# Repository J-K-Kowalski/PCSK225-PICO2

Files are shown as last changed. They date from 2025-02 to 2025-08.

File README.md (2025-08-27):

# PCSK225-PICO2 SDR Receiver

<ul>
<li>2025-08-27 - Documentation</li>
<li>2025-02-25 - First version of the project</li>
</ul>

## Overview

<p>PCSK225-PICO2 is a compact, low‑cost software defined receiver designed to decode the 225 kHz Polish time signal transmitted from Solec Kujawski. The design is built around the Raspberry Pi Pico 2 (RP2350) module and supports two signal acquisition paths:

- Direct sampling with a high‑speed external ADC (ADS7049)
- Optional SSB down‑conversion using a Si4537‑D60 tuner, enabling baseband sampling with the RP2350’s internal ADC

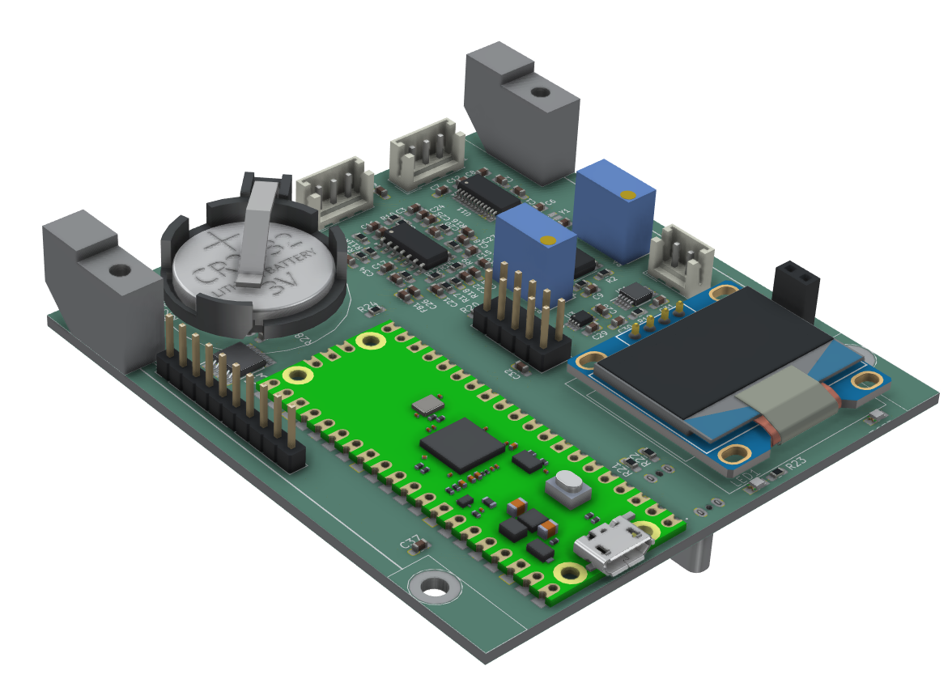
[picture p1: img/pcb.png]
 

<p>The board integrates a precision RTC, local display, I/O expansion, audio output, and multiple user I/Os, making it a self‑contained platform for time‑signal experiments and SDR development.

## Key Features

- MCU: Raspberry Pi Pico 2 (RP2350) module
- Direct RF sampling: ADS7049 12‑bit, high‑speed SPI ADC connected to the RP2350 (supports ~225 kHz IF/baseband sampling)
- Optional tuner: Si4537‑D60 for SSB-style down‑conversion to low IF/baseband for sampling by the RP2350 internal ADC
- RF front end:
    - Active 6‑pole Butterworth band‑pass amplifier around TLV9064 (U2) centered on 225 kHz
    - Output/driver amplifier for Si4537 based on TLV9062 (U1)
    - TMUX1204 analog multiplexer (IC1) for flexible signal routing between ADCs and front‑end nodes
- Timing: DS3231 RTC with CR2032 backup battery for stable timekeeping and 1 Hz/32 kHz outputs
- Displays:
    - On‑board 0.96" I2C OLED (SSD1306)
    - Header for an external graphic LCD
- I/O expansion and storage:
    - PCA9500 I2C port expander with integrated EEPROM for configuration storage
- Connectivity and power:
    - Micro‑USB (Pico 2)
    - USB‑C connector for powering the receiver and PC connectivity
- User I/O:
    - 8 general‑purpose digital I/O lines on headers
    - PWM‑driven speaker/buzzer output with buffer stage
- Form factor: single PCB with Pico 2 module, mounting holes, and on‑board connectors
- See pcb.jpg for a 3D view of the assembled board

## Signal Paths

- Direct 225 kHz path:

1) Antenna/RF input → active BPF (U2 TLV9064) → analog mux (IC1) → ADS7049 → RP2350 via SPI/DMA
2) Intended for coherent sampling/decoding of the Polish 225 kHz time code
- Optional SSB/down‑conversion path:

1) RF input → Si4537‑D60 → low‑IF/baseband → output amplifier (U1 TLV9062) → RP2350 internal ADC
2) Useful for alternative demodulation modes and experiments

## Subsystem Details

- Active BPF: 6‑pole Butterworth around 225 kHz using TLV9064 quad op‑amp, input protection, and gain‑setting network
- Analog MUX: TMUX1204 routes filtered RF to the external ADC or other measurement points
- External ADC: ADS7049 low‑latency, SPI, suited for continuous streaming to RP2350 (DMA recommended)
- RTC: DS3231SN provides INT/SQW and 32 kHz outputs; backed by CR2032 cell
- Displays:
    - SSD1306 OLED on I2C bus (address configurable via jumpers)
    - External LCD header with SPI/I2C signals as routed on the schematic
- I2C Expander/EEPROM: PCA9500 provides extra GPIO and non‑volatile storage for calibration and user settings
- Audio: small speaker output driven from MCU PWM through a buffer (74LVC1G34) and filtering
- Power:
    - 3V3 rail with local decoupling (X5R/COG capacitors as noted)
    - USB‑C and Micro‑USB power options; VSYS routed to Pico 2
    - Ferrite bead and RC elements for analog rail cleanliness

## Firmware Notes

- Platform: Arduino core for RP2040/RP2350 or Pico SDK (C/C++)
- Recommended peripherals:
    - SPI DMA for ADS7049 streaming
    - PIO or timers for precise sampling clocks if needed
    - I2C for OLED, RTC, and PCA9500
    - PWM for speaker/buzzer output
- Example tasks:
    - 225 kHz band‑limited sampling and digital demodulation/decoding (e‑Czas/time code)
    - SSB/low‑IF capture via Si4537 with on‑chip ADC
    - UTC timekeeping using DS3231 and PPS alignment

## Connectors and Interfaces

- Pico 2 module header exposes GP0…GP21, ADC pins, SWD, 3V3, VBUS, VSYS
- OLED I2C header and external LCD header
- USB‑C and Micro‑USB
- 8x GPIO header for user applications
- RF input and test headers as shown on the schematic
- Speaker/buzzer connector

## Bill of Main ICs

- RP2350 (Raspberry Pi Pico 2 module)
- ADS7049 (external high‑speed ADC)
- Si4537‑D60 (optional tuner/down‑converter)
- TLV9064 (quad op‑amp, BPF and buffering)
- TLV9062 (dual op‑amp, output driver)
- TMUX1204 (analog multiplexer)
- DS3231SN (RTC)
- PCA9500 (I2C GPIO expander + EEPROM)
- SSD1306 (OLED controller)

## Status

- Hardware: Rev. 2 schematic/PCB
- Image: see pcb.jpg for the assembled PCB render
- Firmware: work in progress

## License

- Hardware and firmware: A permissive license similar to the BSD 2-Clause License, but with a 3rd clause that prohibits others from using the name of the copyright holder or its contributors to promote derived products without written consent.

## Acknowledgements

- Designed by <b>KJK Innovations</b> for research and development of low‑frequency time‑signal receivers and SDR experimentation.

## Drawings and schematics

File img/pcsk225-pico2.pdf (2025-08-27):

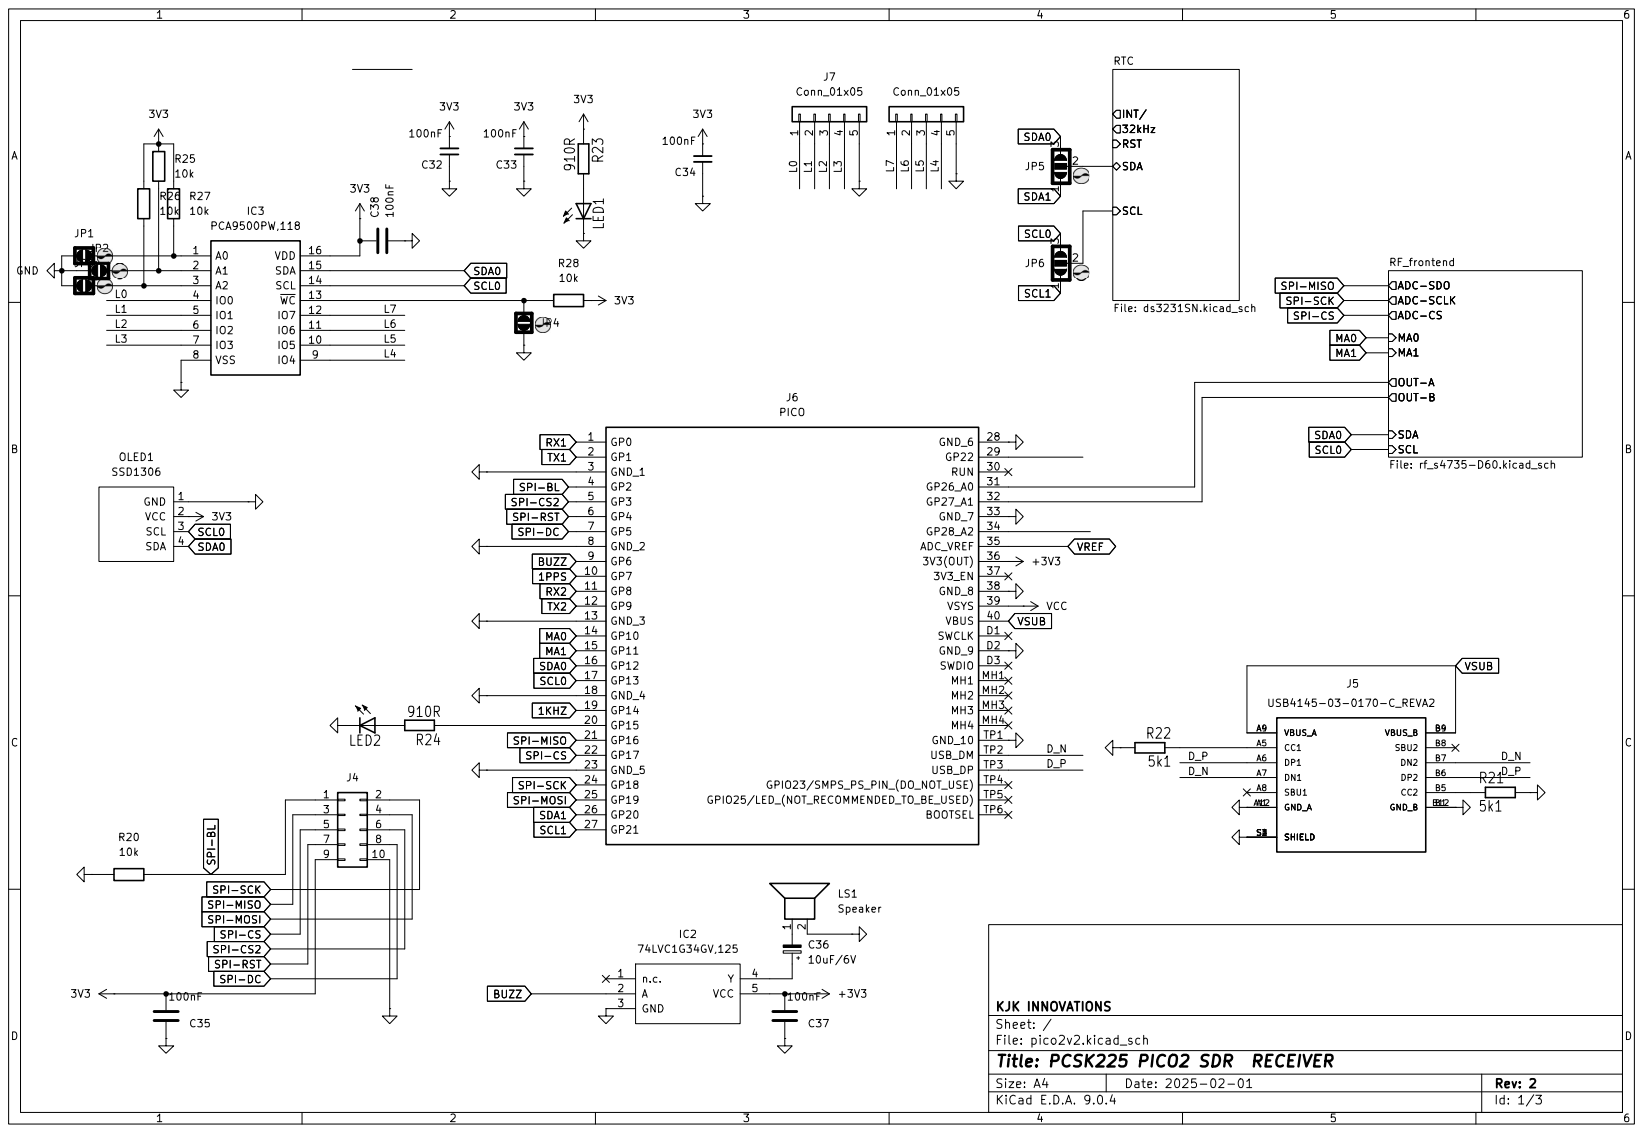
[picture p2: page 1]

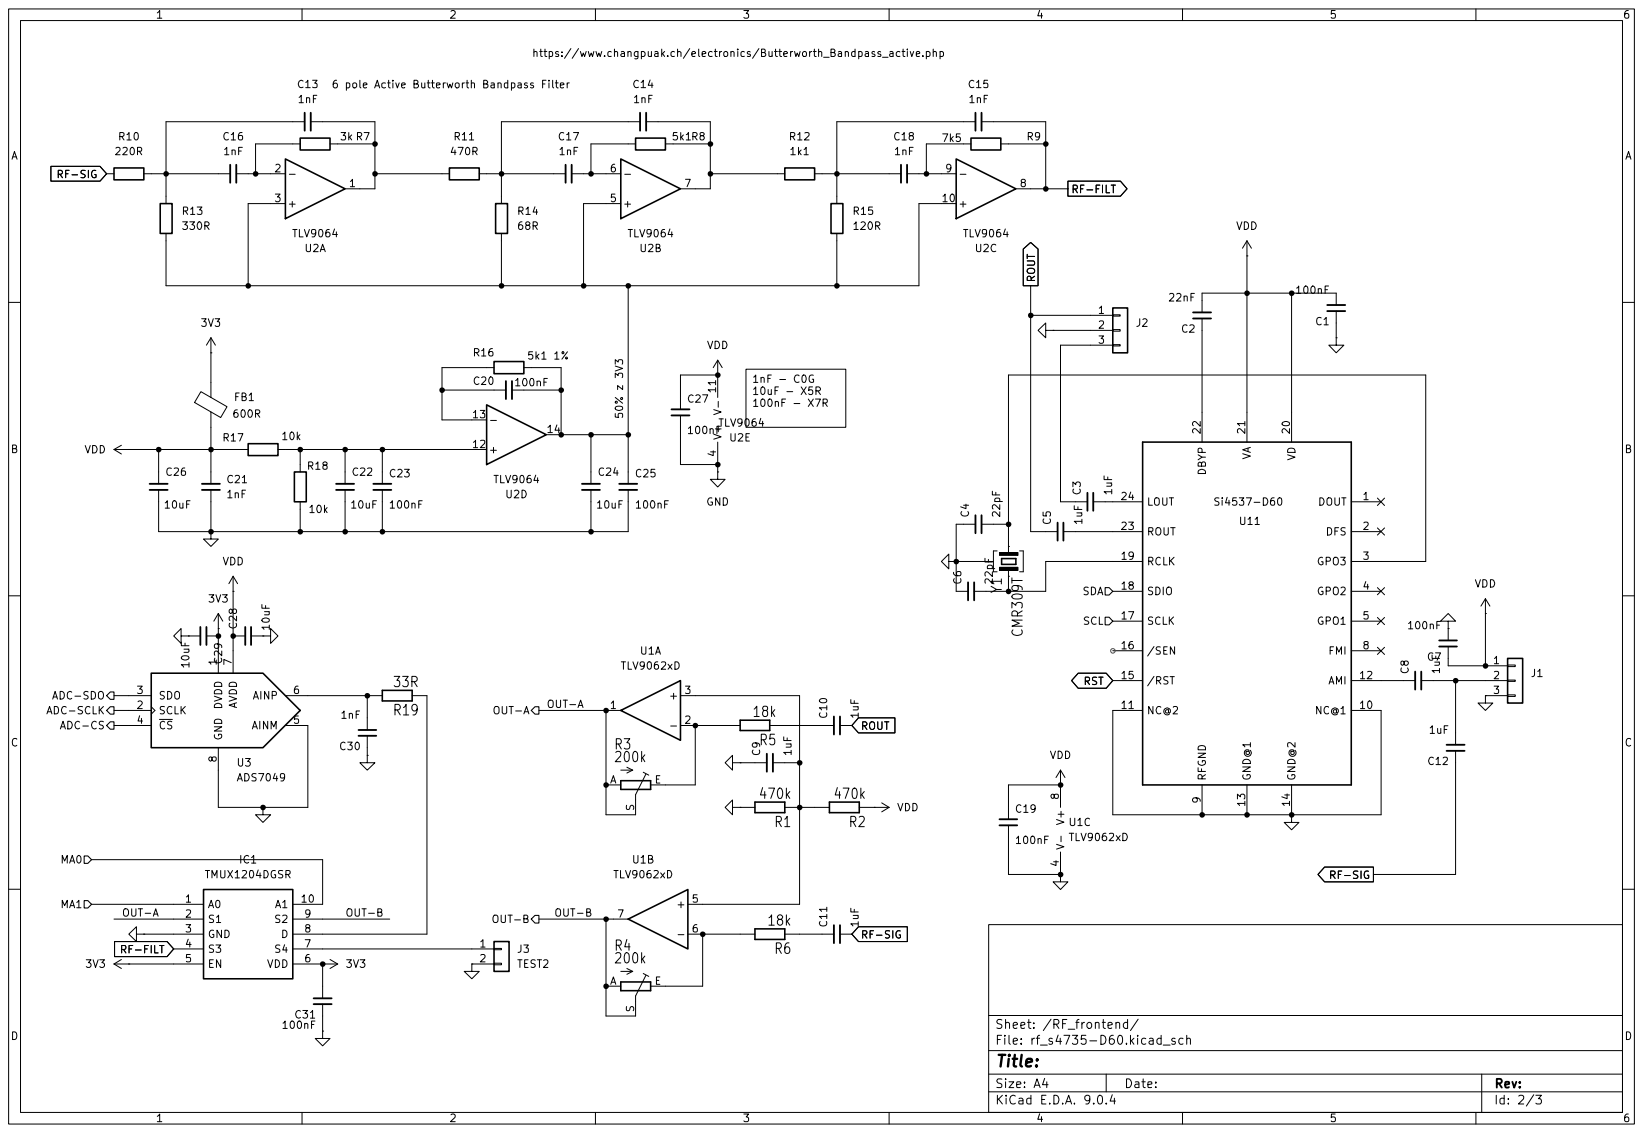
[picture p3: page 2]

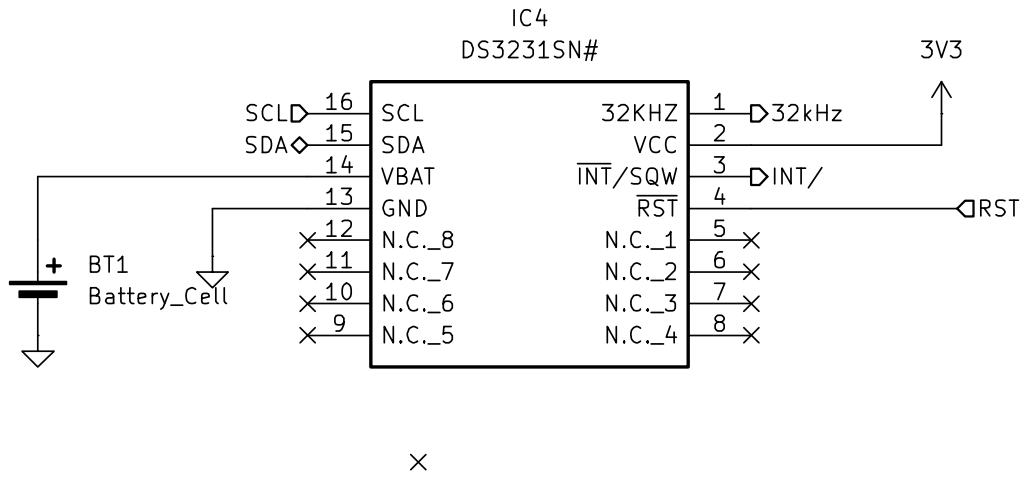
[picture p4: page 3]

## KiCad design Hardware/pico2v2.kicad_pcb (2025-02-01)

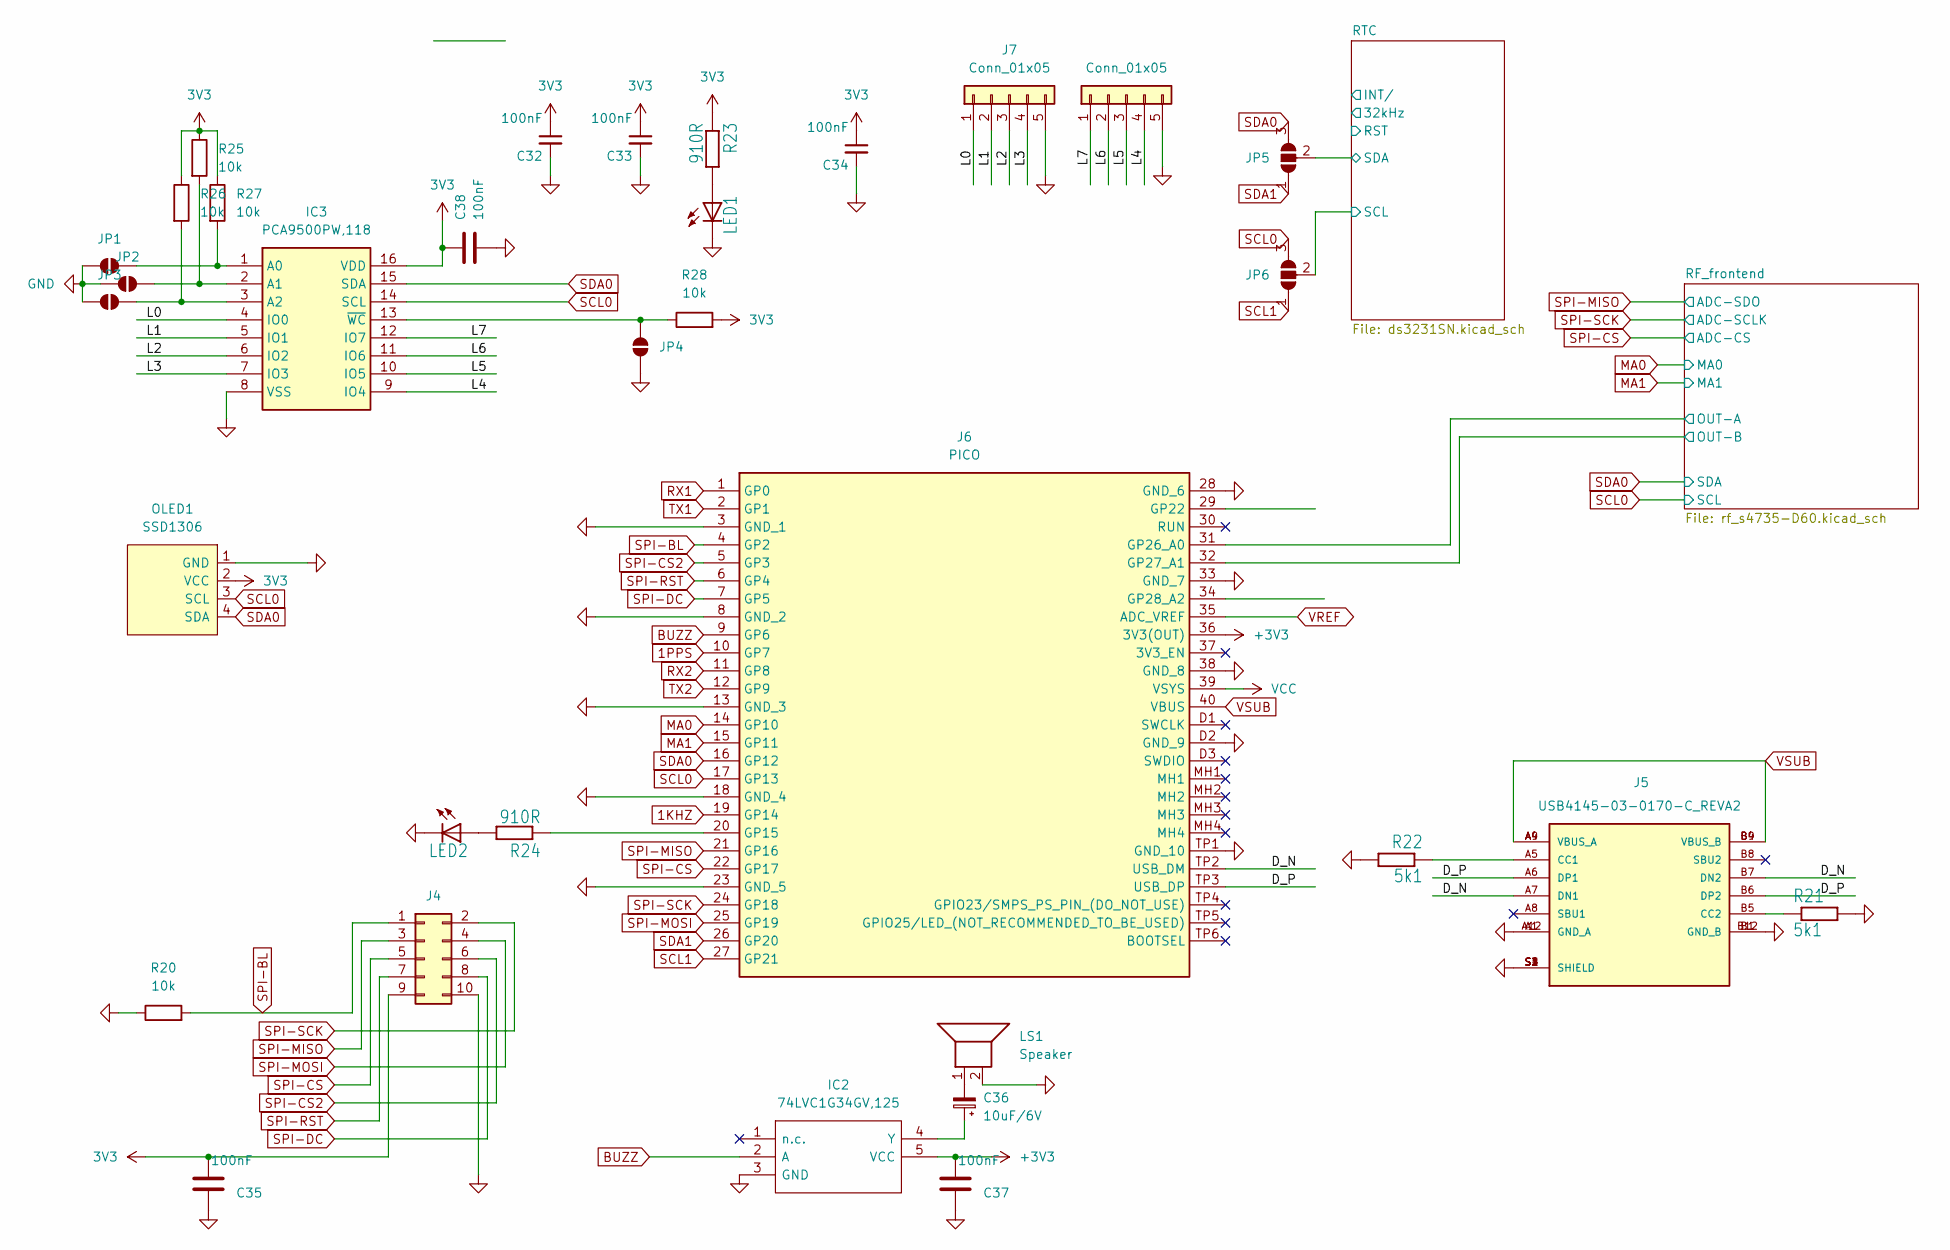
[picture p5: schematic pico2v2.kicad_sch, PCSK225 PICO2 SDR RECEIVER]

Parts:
C32, C33, C34, C35, C37, C38: 100nF; C_0603_1608Metric_Pad1.08x0.95mm_HandSolder
C36: 10uF/6V; C_0805_2012Metric_Pad1.18x1.45mm_HandSolder
Connector_PinHeader_2.54mm:PinHeader_1x05_P2.54mm_Vertical1: Conn_01x05; PinHeader_1x05_P2.54mm_Vertical
IC2: 74LVC1G34GV,125; SOT95P275X110-5N; Manufacturer_Part_Number 74LVC1G34GV,125; Mouser Part Number 771-LVC1G34GV125
IC3: PCA9500PW,118; SOP65P640X110-16N; Mouser Part Number 771-PCA9500PW-T
J4: Conn_02x05_Odd_Even; PinHeader_2x05_P2.54mm_Vertical
J5: USB4145-03-0170-C_REVA2; GCT_USB4145-03-0170-C_REVA2; PARTREV A2
J6: PICO; Manufacturer_Part_Number PICO
J7: Conn_01x05; PinHeader_1x05_P2.54mm_Vertical
JP1, JP2, JP3, JP4: SolderJumper_2_Open; SolderJumper-2_P1.3mm_Open_RoundedPad1.0x1.5mm
JP5, JP6: SolderJumper_3_Open; SolderJumper-3_P1.3mm_Open_RoundedPad1.0x1.5mm
LED1, LED2: LEDCHIPLED_0805; CHIP-LED0805
LS1: Speaker; PinSocket_1x02_P2.54mm_Vertical
OLED1: SSD1306; 128x64OLED
R20, R25, R26, R27, R28: 10k; R_0603_1608Metric_Pad0.98x0.95mm_HandSolder
R21, R22: 5k1; R_0603_1608Metric_Pad0.98x0.95mm_HandSolder
R23, R24: 910R; R_0603_1608Metric_Pad0.98x0.95mm_HandSolder

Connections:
1KHZ: J6.19 (GP14)
1PPS: J6.10 (GP7)
3V3: C32.1, C33.1, C34.1, C35.2, C38.1, IC3.16 (VDD), J4.9, OLED1.2 (VCC), R23.1, R25.1, R26.1, R27.1, R28.2; also elsewhere on the board
+3V3: C37.2, IC2.5 (VCC), J6.36 (3V3(OUT))
/D_N: J5.A7 (DN1), J5.B7 (DN2), J6.42, J6.TP2 (USB_DM)
/D_P: J5.A6 (DP1), J5.B6 (DP2), J6.42, J6.TP3 (USB_DP)
/L0: IC3.4 (IO0), J7.1
/L1: IC3.5 (IO1), J7.2
/L2: IC3.6 (IO2), J7.3
/L3: IC3.7 (IO3), J7.4
/L4: Connector_PinHeader_2.54mm:PinHeader_1x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.4, IC3.9 (IO4)
/L5: Connector_PinHeader_2.54mm:PinHeader_1x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.3, IC3.10 (IO5)
/L6: Connector_PinHeader_2.54mm:PinHeader_1x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.2, IC3.11 (IO6)
/L7: Connector_PinHeader_2.54mm:PinHeader_1x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.1, IC3.12 (IO7)
/RF_frontend/OUT-A: J6.31 (GP26_A0); also elsewhere on the board
/RF_frontend/OUT-B: J6.32 (GP27_A1); also elsewhere on the board
/RTC/SCL: JP6.2 (C); also elsewhere on the board
/RTC/SDA: JP5.2 (C); also elsewhere on the board
BUZZ: IC2.2 (A), J6.9 (GP6)
GND: C32.2, C33.2, C34.2, C35.1, C37.1, C38.2, Connector_PinHeader_2.54mm:PinHeader_1x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.5, IC2.3 (GND), IC3.8 (VSS), J4.10, J5.A1 (GND_A), J5.A12 (GND_A), J5.B1 (GND_B), J5.B12 (GND_B), J5.S1 (SHIELD), J5.S2 (SHIELD), J5.S3 (SHIELD), J5.S4 (SHIELD), J6.3 (GND_1), J6.8 (GND_2), J6.13 (GND_3), J6.18 (GND_4), J6.23 (GND_5), J6.28 (GND_6), J6.33 (GND_7), J6.38 (GND_8), J6.42, J6.D2 (GND_9), J6.TP1 (GND_10), J7.5, JP1.2 (B), JP2.2 (B), JP3.2 (B), JP4.2 (B), LED1.C, LED2.C, LS1.2, OLED1.1 (GND), R20.1, R21.2, R22.2; also elsewhere on the board
MA0: J6.14 (GP10); also elsewhere on the board
MA1: J6.15 (GP11); also elsewhere on the board
unnamed: C36.2, LS1.1
unnamed: C36.1, IC2.4 (Y)
unnamed: IC3.1 (A0), JP1.1 (A), R27.2
unnamed: IC3.2 (A1), JP2.1 (A), R25.2
unnamed: IC3.3 (A2), JP3.1 (A), R26.2
unnamed: IC3.13 (~WC), JP4.1 (A), R28.1
unnamed: J5.A5 (CC1), R22.1
unnamed: J5.B5 (CC2), R21.1
unnamed: J6.20 (GP15), R24.1
unnamed: LED1.A, R23.2
unnamed: LED2.A, R24.2
RX1: J6.1 (GP0)
RX2: J6.11 (GP8)
SCL0: IC3.14 (SCL), J6.17 (GP13), JP6.3 (B), OLED1.3 (SCL); also elsewhere on the board
SCL1: J6.27 (GP21), JP6.1 (A)
SDA0: IC3.15 (SDA), J6.16 (GP12), JP5.3 (B), OLED1.4 (SDA); also elsewhere on the board
SDA1: J6.26 (GP20), JP5.1 (A)
SPI-BL: J4.1, J6.4 (GP2), R20.2
SPI-CS: J4.5, J6.22 (GP17); also elsewhere on the board
SPI-CS2: J4.6, J6.5 (GP3)
SPI-DC: J4.8, J6.7 (GP5)
SPI-MISO: J4.3, J6.21 (GP16); also elsewhere on the board
SPI-MOSI: J4.4, J6.25 (GP19)
SPI-RST: J4.7, J6.6 (GP4)
SPI-SCK: J4.2, J6.24 (GP18); also elsewhere on the board
TX1: J6.2 (GP1)
TX2: J6.12 (GP9)
VCC: J6.39 (VSYS)
VREF: J6.35 (ADC_VREF)
VSUB: J5.A4 (VBUS_A), J5.A9 (VBUS_A), J5.B4 (VBUS_B), J5.B9 (VBUS_B), J6.40 (VBUS)

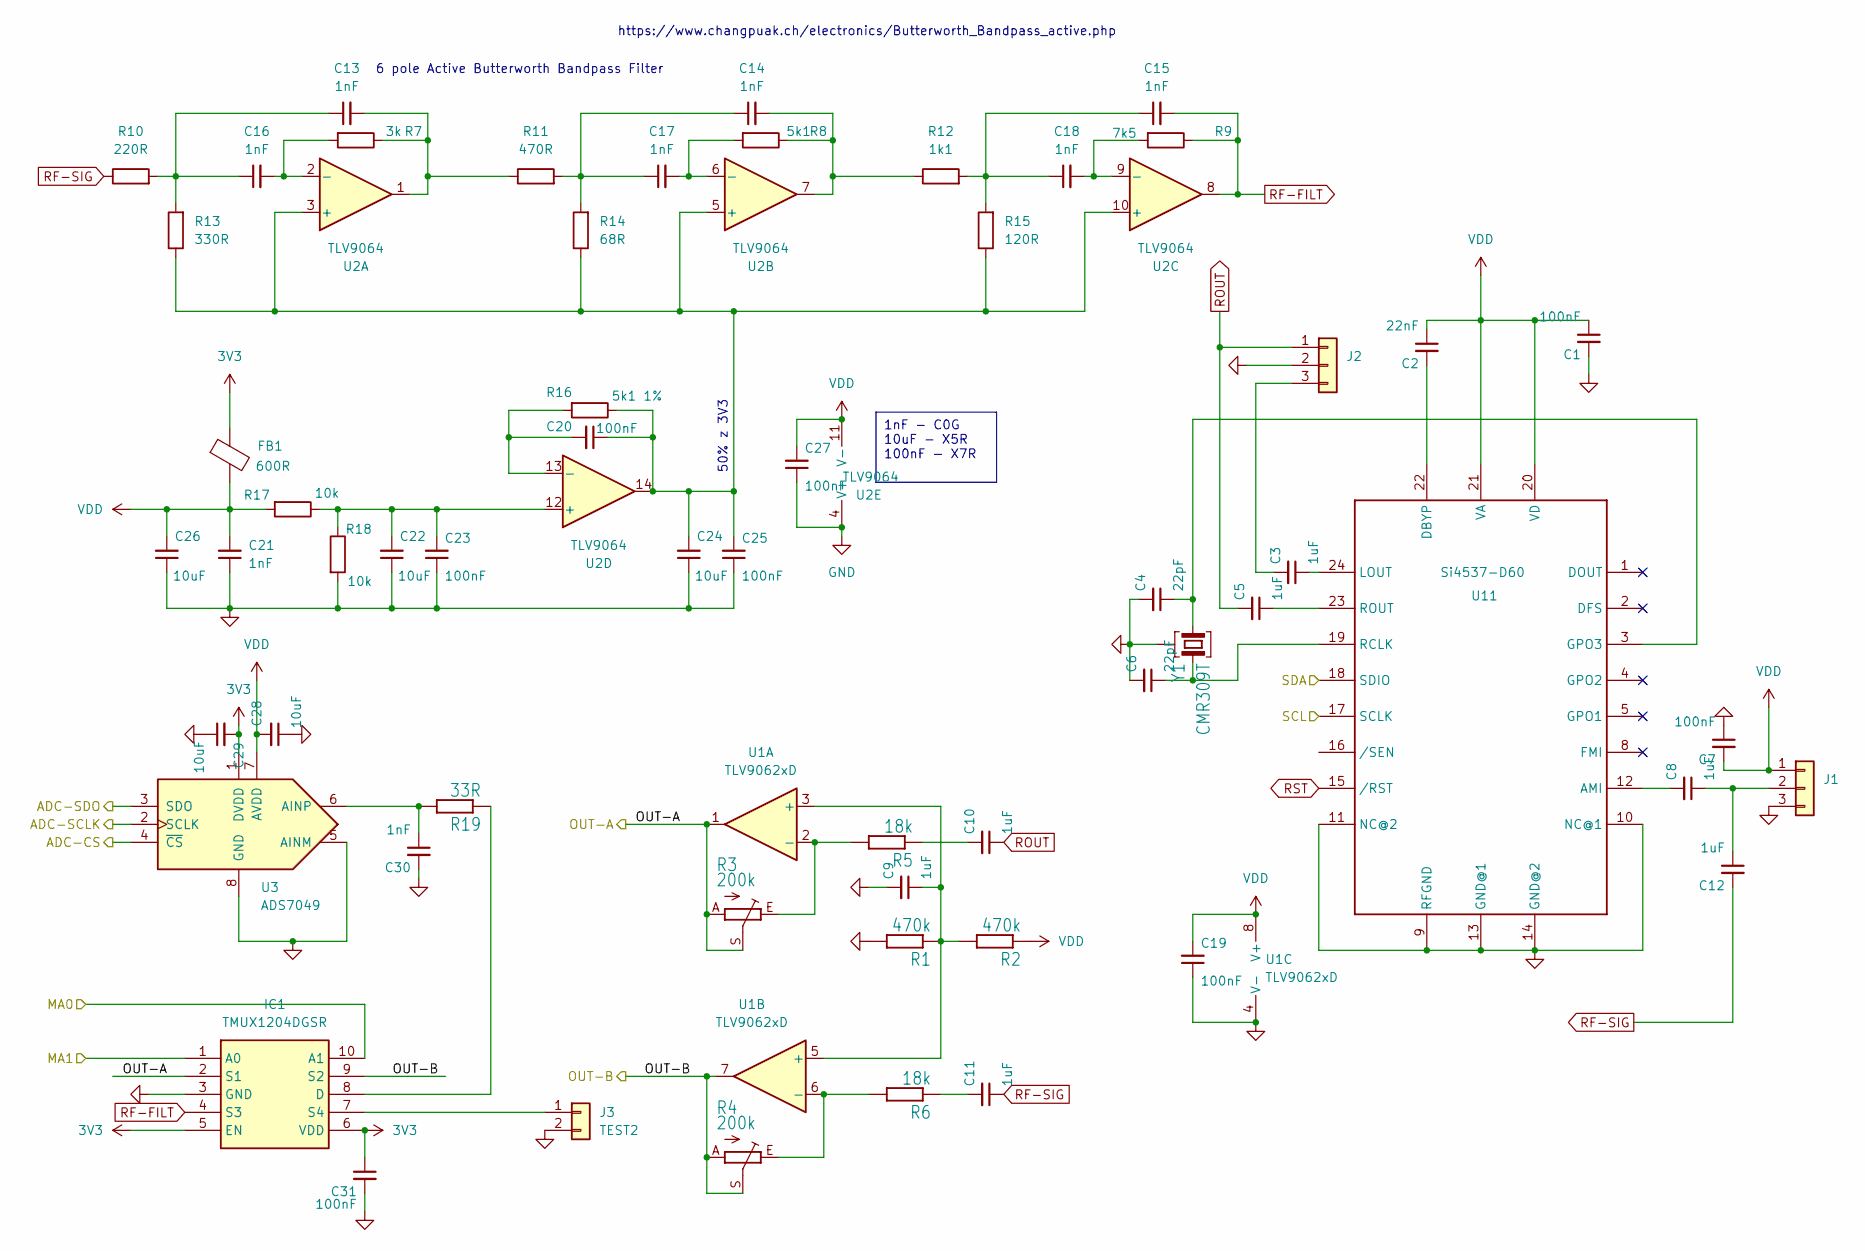
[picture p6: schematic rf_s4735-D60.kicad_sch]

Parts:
C1, C7, C19, C20, C23, C25, C27, C31: 100nF; C_0603_1608Metric_Pad1.08x0.95mm_HandSolder
C2: 22nF; C_0603_1608Metric_Pad1.08x0.95mm_HandSolder
C3, C5, C8, C9, C10, C11, C12: 1uF; C_0603_1608Metric_Pad1.08x0.95mm_HandSolder
C4, C6: 22pF; C_0603_1608Metric_Pad1.08x0.95mm_HandSolder
C13, C14, C15, C16, C17, C18, C21, C30: 1nF; C_0603_1608Metric_Pad1.08x0.95mm_HandSolder
C22, C24, C26, C28, C29: 10uF; C_0603_1608Metric_Pad1.08x0.95mm_HandSolder
FB1: 600R; C_0603_1608Metric_Pad1.08x0.95mm_HandSolder
IC1: TMUX1204DGSR; SOP50P490X110-10N; Mouser Part Number 595-TMUX1204DGSR
J1: ANT1; JST_EH_B3B-EH-A_1x03_P2.50mm_Vertical
J2: TEST1; JST_EH_B3B-EH-A_1x03_P2.50mm_Vertical
J3: TEST2; JST_EH_B2B-EH-A_1x02_P2.50mm_Vertical
R1, R2: 470k; R_0603_1608Metric_Pad0.98x0.95mm_HandSolder
R3, R4: 200k; RJ9W
R5, R6: 18k; R_0603_1608Metric_Pad0.98x0.95mm_HandSolder
R7: 3k; R_0603_1608Metric_Pad0.98x0.95mm_HandSolder
R8, R16: 5k1; R_0603_1608Metric_Pad0.98x0.95mm_HandSolder
R9: 7k5; R_0603_1608Metric_Pad0.98x0.95mm_HandSolder
R10: 220R; R_0603_1608Metric_Pad0.98x0.95mm_HandSolder
R11: 470R; R_0603_1608Metric_Pad0.98x0.95mm_HandSolder
R12: 1k1; R_0603_1608Metric_Pad0.98x0.95mm_HandSolder
R13: 330R; R_0603_1608Metric_Pad0.98x0.95mm_HandSolder
R14: 68R; R_0603_1608Metric_Pad0.98x0.95mm_HandSolder
R15: 120R; R_0603_1608Metric_Pad0.98x0.95mm_HandSolder
R17, R18: 10k; R_0603_1608Metric_Pad0.98x0.95mm_HandSolder
R19: 33R; R_0603_1608Metric_Pad0.98x0.95mm_HandSolder
U1: TLV9062xD; SOIC-8_3.9x4.9mm_P1.27mm
U2: TLV9064; SOIC-14_3.9x8.7mm_P1.27mm
U3: ADS7049; VSSOP-8_2.3x2mm_P0.5mm
U11: Si4537-D60; SSOP-24_3.9x8.7mm_P0.635mm
Y1: CMR309T; Crystal_SMD_MicroCrystal_MS3V-T1R

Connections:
3V3: C29.2, C31.1, FB1.1, IC1.5 (EN), IC1.6 (VDD), U3.1 (DVDD); also elsewhere on the board
/RF_frontend/OUT-A: IC1.2 (S1), R3.A, R3.S, U1.1; also elsewhere on the board
/RF_frontend/OUT-B: IC1.9 (S2), R4.A, R4.S, U1.7; also elsewhere on the board
GND: C1.2, C4.2, C6.2, C7.1, C9.2, C19.1, C21.1, C22.1, C23.1, C24.1, C25.1, C26.1, C27.1, C28.1, C29.1, C30.2, C31.2, IC1.3 (GND), J1.3, J2.2, J3.2, R1.2, R18.2, U1.4 (V-), U2.4 (V+), U3.5 (AINM), U3.8 (GND), U11.9 (RFGND), U11.10 (NC@1), U11.11 (NC@2), U11.13 (GND@1), U11.14 (GND@2), Y1.3 (G); also elsewhere on the board
MA0: IC1.10 (A1); also elsewhere on the board
MA1: IC1.1 (A0); also elsewhere on the board
unnamed: C10.2, R5.1
unnamed: C11.2, R6.1
unnamed: C13.1, C16.1, R10.2, R13.2
unnamed: C13.2, R7.1, R11.1, U2.1
unnamed: C14.1, C17.1, R11.2, R14.2
unnamed: C14.2, R8.1, R12.1, U2.7
unnamed: C15.1, C18.1, R12.2, R15.2
unnamed: IC1.8 (D), R19.1
unnamed: IC1.7 (S4), J3.1
unnamed: C8.1, C12.1, J1.2
unnamed: C3.2, J2.3
unnamed: C9.1, R1.1, R2.2, U1.3 (+), U1.5 (+)
unnamed: R3.E, R5.2, U1.2 (-)
unnamed: R4.E, R6.2, U1.6 (-)
unnamed: C20.1, C24.2, C25.2, R13.1, R14.1, R15.1, R16.1, U2.3 (+), U2.5 (+), U2.10 (+), U2.14
unnamed: C16.2, R7.2, U2.2 (-)
unnamed: C17.2, R8.2, U2.6 (-)
unnamed: C18.2, R9.2, U2.9 (-)
unnamed: C22.2, C23.2, R17.1, R18.1, U2.12 (+)
unnamed: C20.2, R16.2, U2.13 (-)
unnamed: C30.1, R19.2, U3.6 (AINP)
unnamed: C8.2, U11.12 (AMI)
unnamed: C2.2, U11.22 (DBYP)
unnamed: C4.1, U11.3 (GPO3), Y1.1
unnamed: C3.1, U11.24 (LOUT)
unnamed: C6.1, U11.19 (RCLK), Y1.2
unnamed: C5.1, U11.23 (ROUT)
RF-FILT: C15.2, IC1.4 (S3), R9.1, U2.8
RF-SIG: C11.1, C12.2, R10.1
ROUT: C5.2, C10.1, J2.1
RST: U11.15 (/RST)
SCL0: U11.17 (SCLK); also elsewhere on the board
SDA0: U11.18 (SDIO); also elsewhere on the board
SPI-CS: U3.4 (~CS); also elsewhere on the board
SPI-MISO: U3.3 (SDO); also elsewhere on the board
SPI-SCK: U3.2 (SCLK); also elsewhere on the board
VDD: C1.1, C2.1, C7.2, C19.2, C21.2, C26.2, C27.2, C28.2, FB1.2, J1.1, R2.1, R17.2, U1.8 (V+), U2.11 (V-), U3.7 (AVDD), U11.20 (VD), U11.21 (VA)

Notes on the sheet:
1nF - C0G 10uF - X5R 100nF - X7R
https://www.changpuak.ch/electronics/Butterworth_Bandpass_active.php
50% z 3V3
6 pole Active Butterworth Bandpass Filter

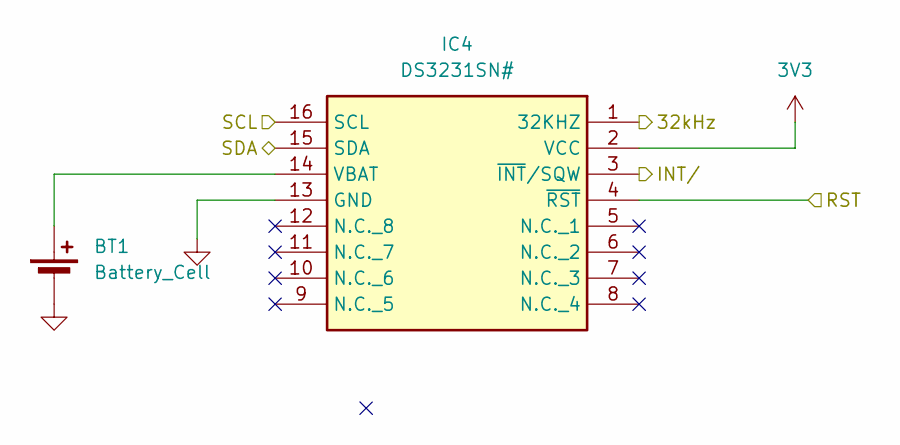
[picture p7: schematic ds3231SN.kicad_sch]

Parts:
BT1: Battery_Cell; BatteryHolder_MYOUNG_BS-07-A1BJ001_CR2032
IC4: DS3231SN#; SOIC127P1032X265-16N; Mouser Part Number 700-DS3231SN#

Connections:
3V3: IC4.2 (VCC); also elsewhere on the board
/RTC/32kHz: IC4.1 (32KHZ)
/RTC/INT/: IC4.3 (~INT/SQW)
/RTC/RST: IC4.4 (~RST)
/RTC/SCL: IC4.16 (SCL); also elsewhere on the board
/RTC/SDA: IC4.15 (SDA); also elsewhere on the board
GND: BT1.2 (-), IC4.13 (GND); also elsewhere on the board
unnamed: BT1.1 (+), IC4.14 (VBAT)

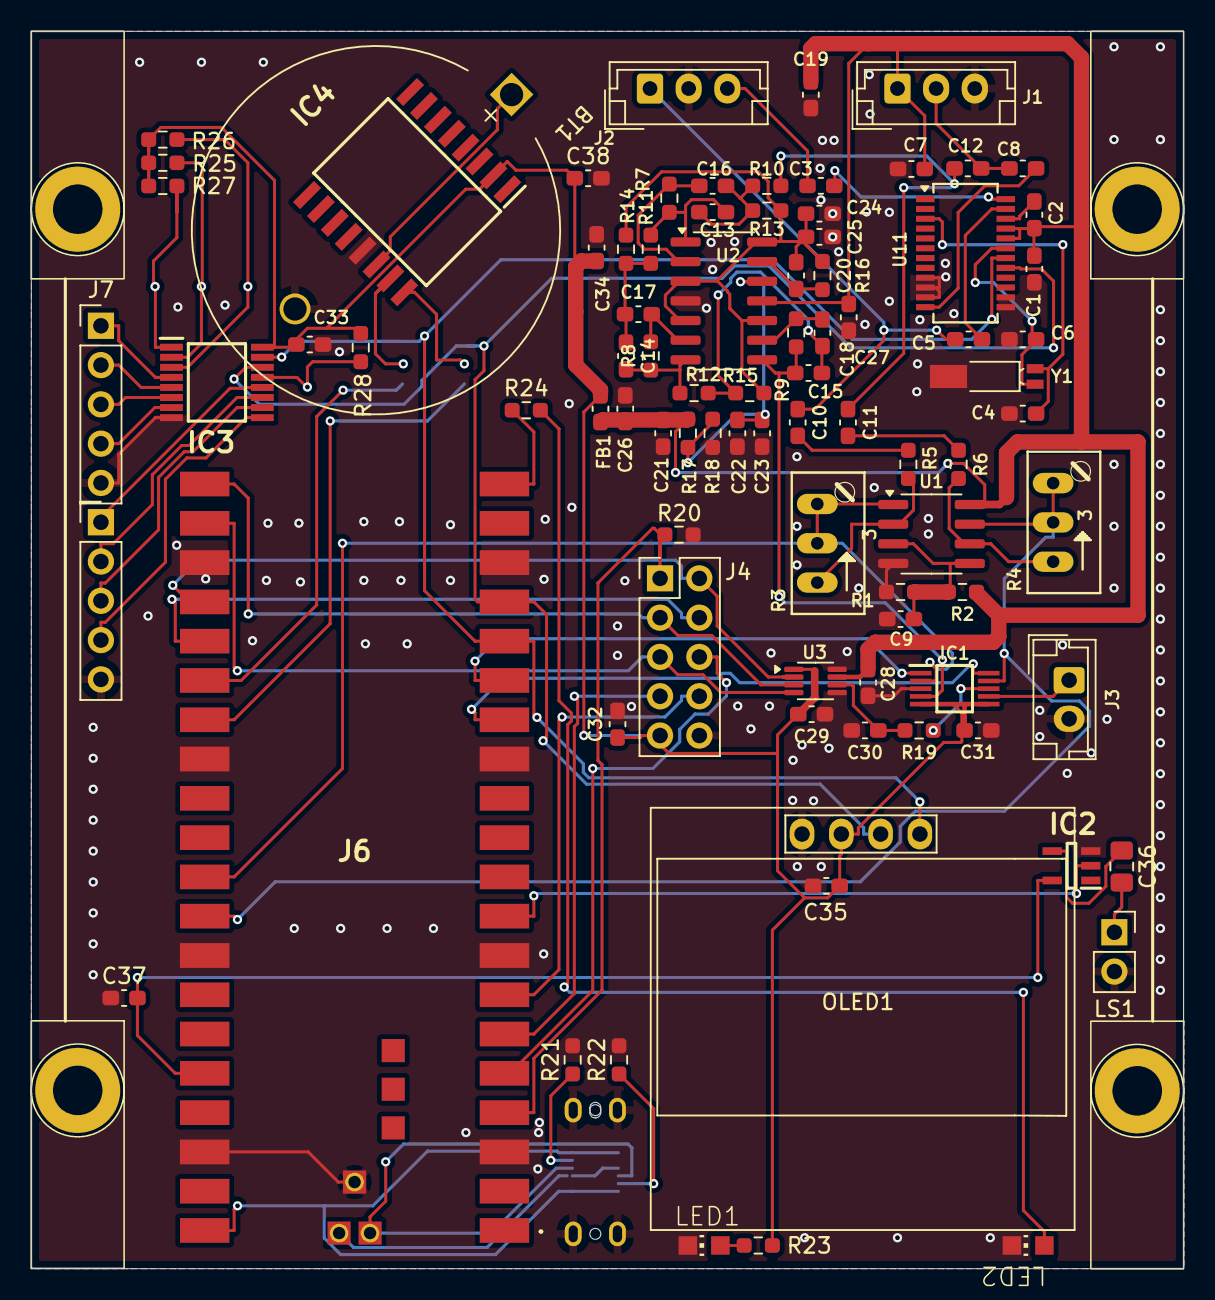
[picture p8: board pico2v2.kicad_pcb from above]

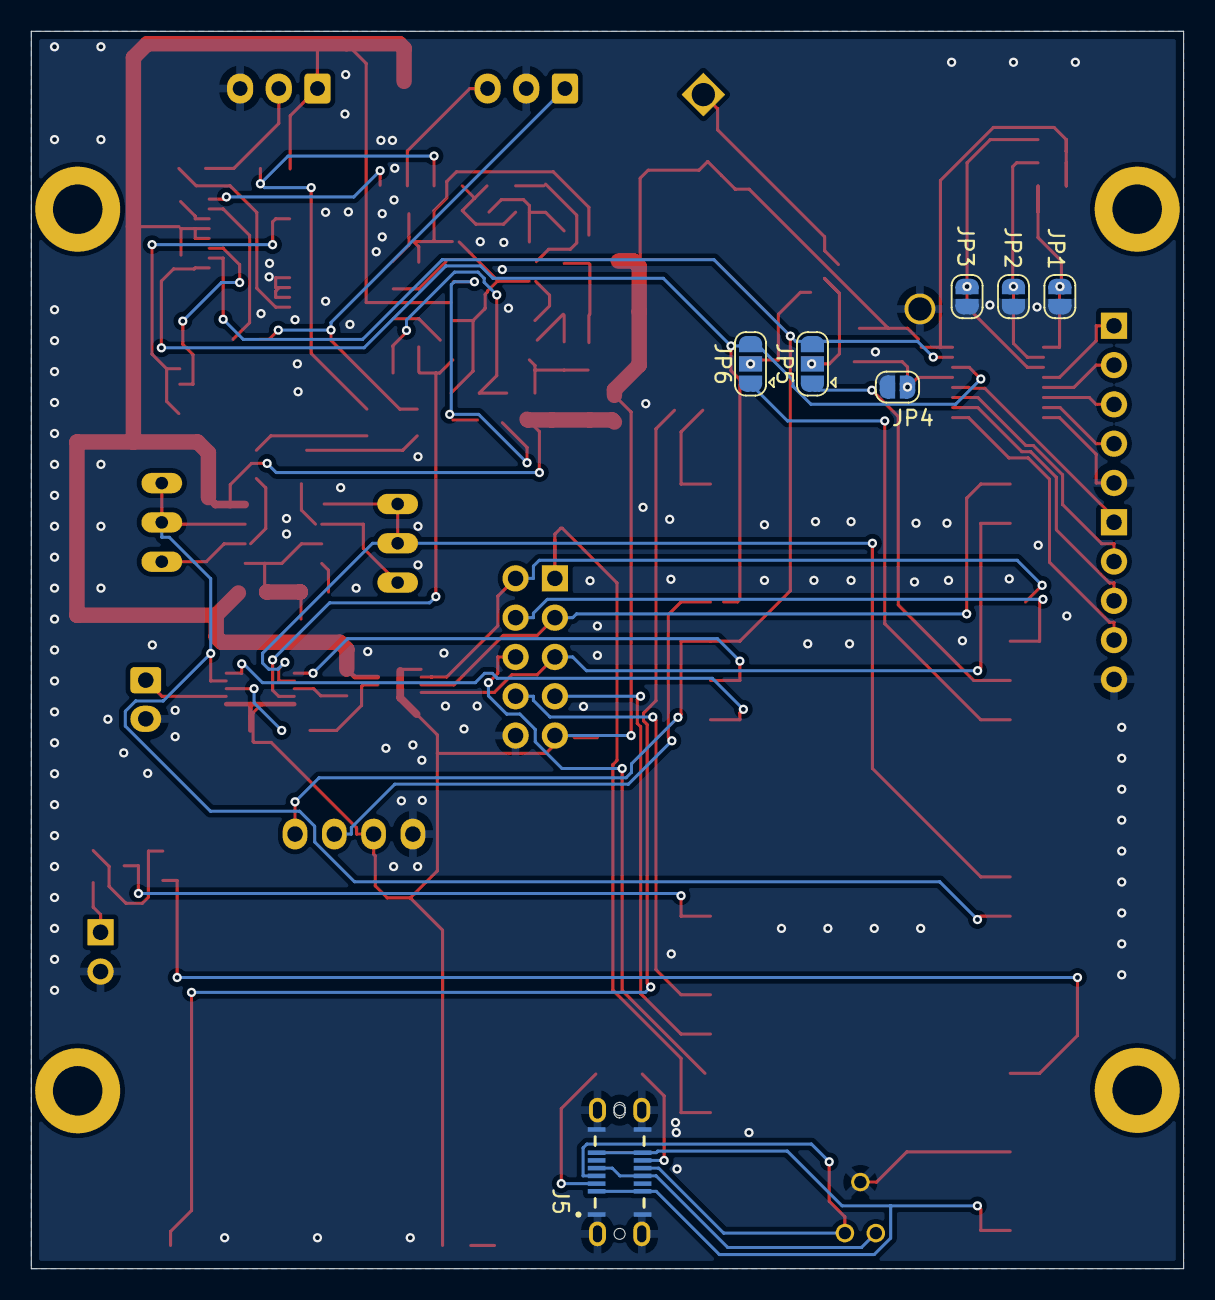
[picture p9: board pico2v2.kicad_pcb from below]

Board: 2 copper layers, 74.5 x 80.0 mm, 99 parts (7 on the bottom side), 76 nets.

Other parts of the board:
PMB1, PMB2, PMB3, PMB4: PMB-1
